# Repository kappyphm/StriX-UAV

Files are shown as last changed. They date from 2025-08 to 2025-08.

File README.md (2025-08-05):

# Small Fixed-Wing UAV Project

## Overview
This repository contains the design, control circuitry, firmware, and hardware assembly instructions for a small fixed-wing Unmanned Aerial Vehicle (UAV). The UAV supports remote control operation with a range of 500m–1km, automatic stabilization, GPS-based autonomous flight, and a return-to-home feature upon signal loss. The system is built around the STM32F103C8T6 microcontroller.

## Features
- **Remote Control**: 6 analog channels and 2 digital channels for precise control via an NRF24L01 module.
- **Flight Controller (FC)**:
  - Decodes control signals from NRF24L01 to manage 2 aileron servos, 1 rudder servo, 1 elevator servo, and 1 brushless motor ESC.
  - Reads UART signals from a GPS module for autonomous flight and return-to-home functionality.
  - Uses I2C IMU (ICM20948) for flight stabilization.
  - Supports firmware flashing and debugging via SWD.
  - Compatible with 2S–3S LiPo batteries, ensuring stable power delivery.
- **Flight Capabilities**:
  - Remote control with effective range of 500m–1km.
  - Automatic stabilization for smooth flight.
  - Autonomous flight via preloaded GPS waypoints.
  - Return-to-home feature on signal loss.

## Hardware Components
### Transmitter (TX) PCB
- **Function**: Captures 6 analog and 2 digital channels from user input.
- **Communication**: Transmits control signals via NRF24L01 module.

### Flight Controller (FC)
- **Microcontroller**: STM32F103C8T6.
- **Function**: Receives 6 PWM and 2 digital channels via NRF24L01.
- **Peripherals**:
  - 2 aileron servos, 1 rudder servo, 1 elevator servo.
  - 1 ESC for brushless motor control.
  - GPS module (UART) for navigation.
  - ICM20948 IMU (I2C) for stabilization.
- **Power**: Supports 2S–3S LiPo batteries with stable power regulation.
- **Debugging**: SWD interface for firmware updates and debugging.

## Contributing
Contributions are welcome! Please follow these steps:
1. Fork the repository.
2. Create a new branch (`git checkout -b feature/your-feature`).
3. Commit your changes (`git commit -m "Add your feature"`).
4. Push to the branch (`git push origin feature/your-feature`).
5. Open a pull request.

## License
This project is licensed under the MIT License. See the `LICENSE` file for details.

## Contact
For questions or suggestions, open an issue or contact [your email or GitHub handle].

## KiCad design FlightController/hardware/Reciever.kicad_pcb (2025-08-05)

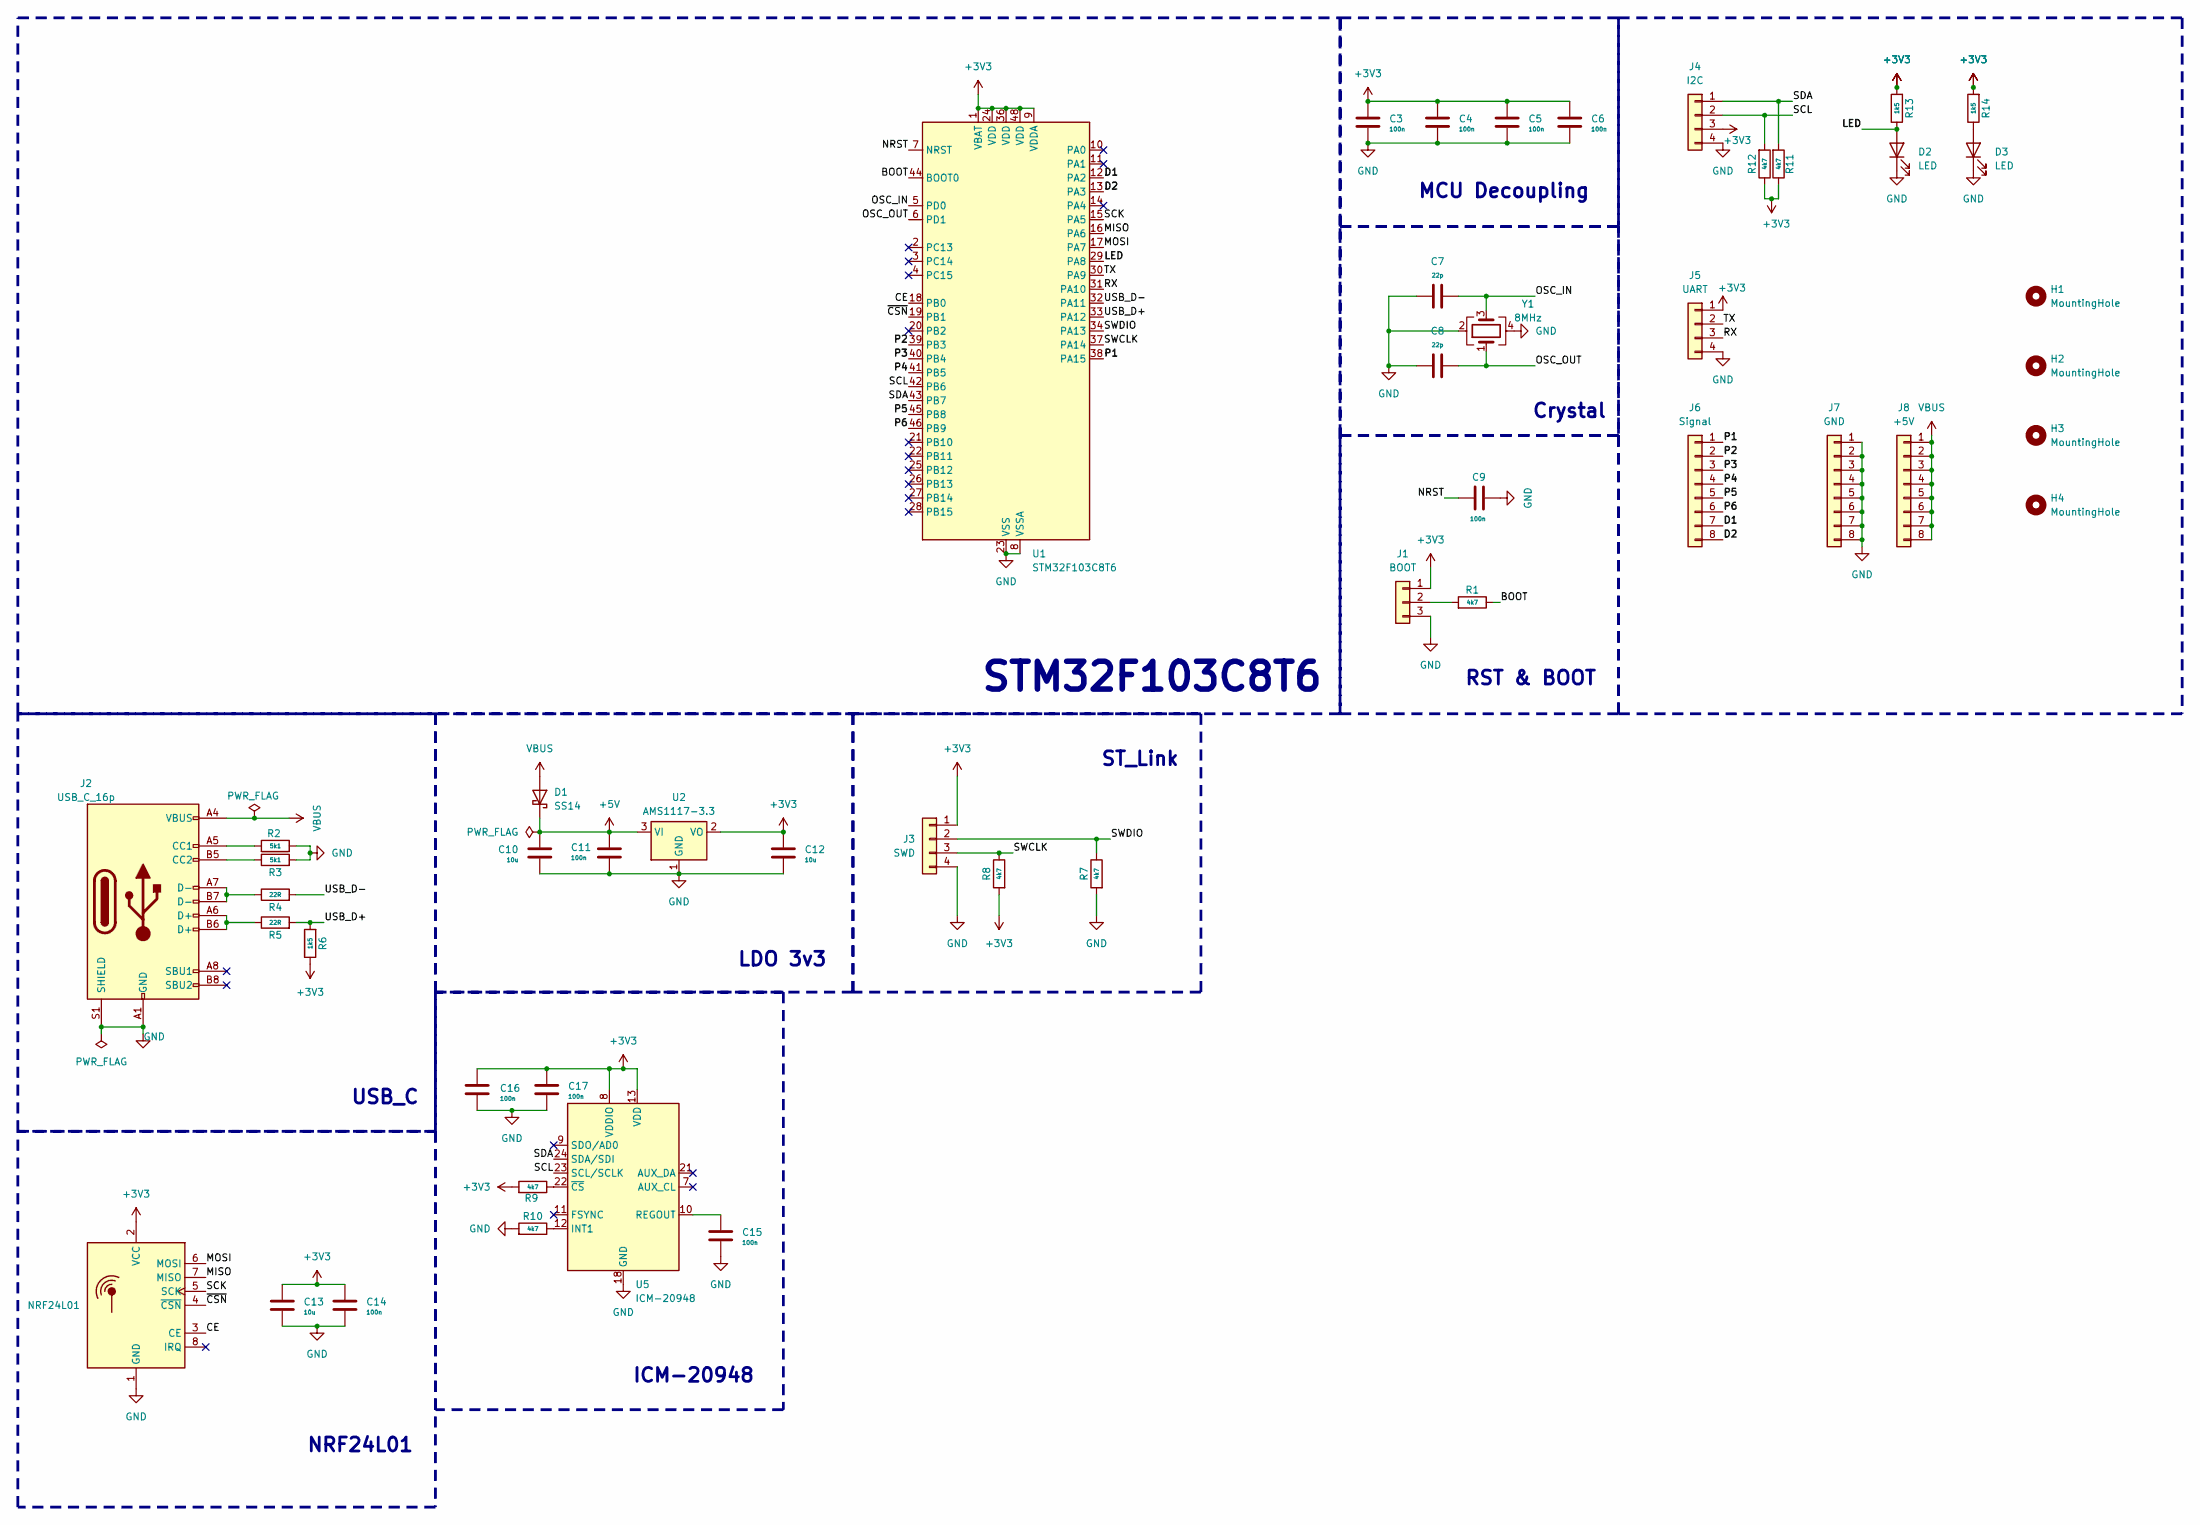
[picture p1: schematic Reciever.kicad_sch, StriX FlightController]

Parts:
C3, C4, C5, C6, C9, C11, C14, C15, C16, C17: 100n; C_0603_1608Metric
C7, C8: 22p; C_0603_1608Metric
C10, C12, C13: 10u; C_0603_1608Metric
D1: SS14; D_SMA
D2, D3: LED; LED_1206_3216Metric
H1, H2, H3, H4: MountingHole; MountingHole_2.5mm
J1: BOOT; PinHeader_1x03_P2.54mm_Vertical
J2: USB_C_16p; USB_C_Receptacle_HRO_TYPE-C-31-M-12
J3: SWD; PinHeader_1x04_P2.54mm_Vertical
J4: I2C; PinHeader_1x04_P2.54mm_Vertical
J5: UART; PinHeader_1x04_P2.54mm_Vertical
J6: Signal; PinHeader_1x08_P2.54mm_Vertical
J7: GND; PinHeader_1x08_P2.54mm_Vertical
J8: +5V; PinHeader_1x08_P2.54mm_Vertical
R1, R7, R8, R9, R10, R11, R12: 4k7; R_0603_1608Metric
R2, R3: 5k1; R_0603_1608Metric
R4, R5: 22R; R_0603_1608Metric
R6, R13, R14: 1k5; R_0603_1608Metric
U1: STM32F103C8T6; LQFP-48_7x7mm_P0.5mm
U2: AMS1117-3.3; SOT-223-3_TabPin2
U4: NRF24L01; NRF24L01_PA_LNA
U5: ICM-20948; InvenSense_QFN-24_3x3mm_P0.4mm
Y1: 8MHz; Crystal_SMD_5032-4Pin_5.0x3.2mm

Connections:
+3V3: C3.1, C4.1, C5.1, C6.1, C12.1, C13.1, C14.1, C16.1, C17.1, J1.1, J3.1, J4.3, J5.1, R6.1, R8.2, R9.2, R11.1, R12.1, R13.2, R14.2, U1.1 (VBAT), U1.9 (VDDA), U1.24 (VDD), U1.36 (VDD), U1.48 (VDD), U2.2 (VO), U4.2 (VCC), U5.8 (VDDIO), U5.13 (VDD)
+5V: C10.1, C11.1, D1.1 (K), U2.3 (VI)
/BOOT: R1.1, U1.44 (BOOT0)
/CE: U1.18 (PB0), U4.3 (CE)
/D1: J6.7, U1.12 (PA2)
/D2: J6.8, U1.13 (PA3)
/LED: D2.2 (A), R13.1, U1.29 (PA8)
/MISO: U1.16 (PA6), U4.7 (MISO)
/MOSI: U1.17 (PA7), U4.6 (MOSI)
/NRST: C9.1, U1.7 (NRST)
/OSC_IN: C7.2, U1.5 (PD0), Y1.3
/OSC_OUT: C8.2, U1.6 (PD1), Y1.1
/P1: J6.1, U1.38 (PA15)
/P2: J6.2, U1.39 (PB3)
/P3: J6.3, U1.40 (PB4)
/P4: J6.4, U1.41 (PB5)
/P5: J6.5, U1.45 (PB8)
/P6: J6.6, U1.46 (PB9)
/RX: J5.3, U1.31 (PA10)
/SCK: U1.15 (PA5), U4.5 (SCK)
/SCL: J4.2, R12.2, U1.42 (PB6), U5.23 (SCL/SCLK)
/SDA: J4.1, R11.2, U1.43 (PB7), U5.24 (SDA/SDI)
/SWCLK: J3.3, R8.1, U1.37 (PA14)
/SWDIO: J3.2, R7.1, U1.34 (PA13)
/TX: J5.2, U1.30 (PA9)
/USB_D+: R5.2, R6.2, U1.33 (PA12)
/USB_D-: R4.2, U1.32 (PA11)
/~CSN: U1.19 (PB1), U4.4 (~CSN)
GND: C3.2, C4.2, C5.2, C6.2, C7.1, C8.1, C9.2, C10.2, C11.2, C12.2, C13.2, C14.2, C15.2, C16.2, C17.2, D2.1 (K), D3.1 (K), J1.3, J2.A1 (GND), J2.A12 (GND), J2.B1 (GND), J2.B12 (GND), J2.S1 (SHIELD), J3.4, J4.4, J5.4, J7.1, J7.2, J7.3, J7.4, J7.5, J7.6, J7.7, J7.8, R2.2, R3.2, R7.2, R10.2, U1.8 (VSSA), U1.23 (VSS), U1.35 (VSS), U1.47 (VSS), U2.1 (GND), U4.1 (GND), U5.18 (GND), U5.20 (GND), Y1.2, Y1.4
unnamed: D3.2 (A), R14.1
unnamed: J1.2, R1.2
unnamed: J2.A5 (CC1), R2.1
unnamed: J2.B5 (CC2), R3.1
unnamed: J2.A6 (D+), J2.B6 (D+), R5.1
unnamed: J2.A7 (D-), J2.B7 (D-), R4.1
unnamed: R10.1, U5.12 (INT1)
unnamed: C15.1, U5.10 (REGOUT)
unnamed: R9.1, U5.22 (~CS)
VBUS: D1.2 (A), J2.A4 (VBUS), J2.A9 (VBUS), J2.B4 (VBUS), J2.B9 (VBUS), J8.1, J8.2, J8.3, J8.4, J8.5, J8.6, J8.7, J8.8

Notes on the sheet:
ST_Link
Crystal
LDO 3v3
USB_C
ICM-20948
RST & BOOT
NRF24L01
STM32F103C8T6
MCU Decoupling

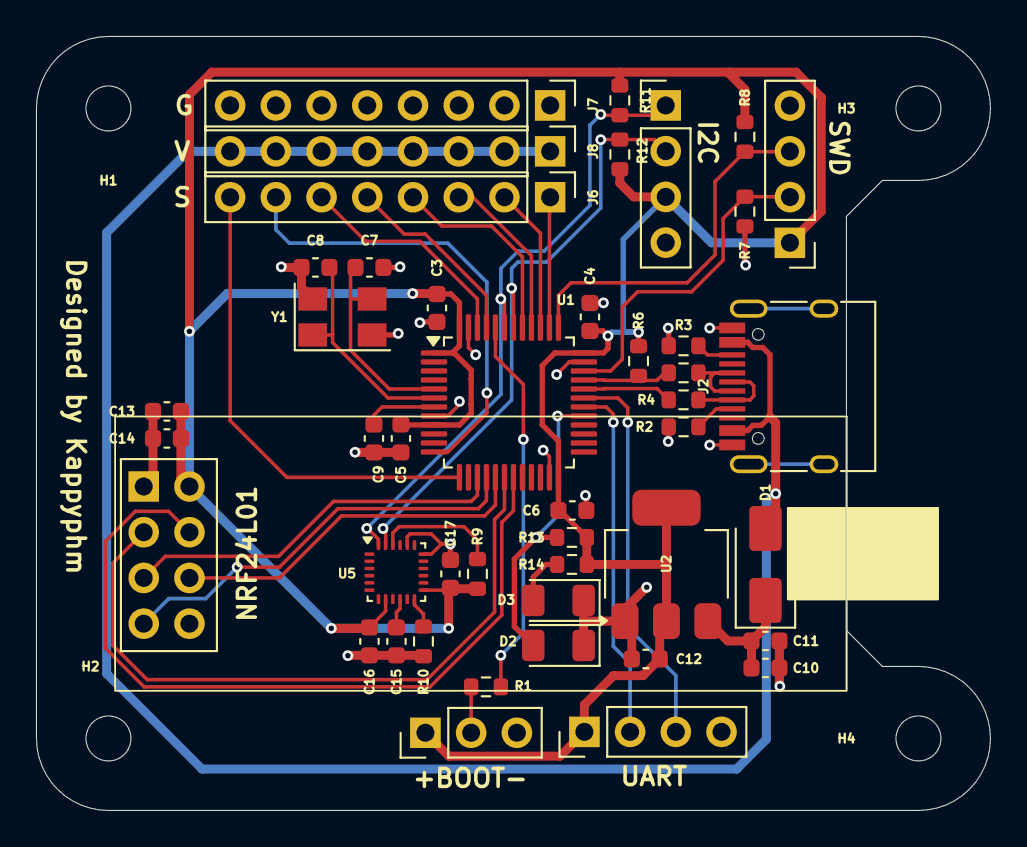
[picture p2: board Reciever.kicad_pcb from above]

Board: 2 copper layers, 53.0 x 43.0 mm, 49 parts (0 on the bottom side), 39 nets.

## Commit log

2025-08-05 Update FlightController hardware StriX-HV-1.0
    [Reciever.kicad_pcb, Reciever.kicad_sch]
2025-08-05 Update README with detailed project overview
    Expanded the README to include a comprehensive overview of the small fixed-wing UAV project, its features, hardware components, repository structure, setup instructions, requirements, contribution guidelines, license, and contact information. This provides clearer guidance for users and contributors.
